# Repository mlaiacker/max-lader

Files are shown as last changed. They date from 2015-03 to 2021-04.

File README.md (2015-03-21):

# max-lader
DIY Battery Charger, 12V Input, 0-25V Output, 5.5A, using AVR
With these components the charger is limited to about 120W and maximum input voltage of about 15V

See also: 
http://mlaiacker.no-ip.org/Modellbau/AVR-Lader/
## Charging
Type | Cells
----|----
LiPo | 1-6
LiFe | 1-7
NiMh/NiCa| 1-16
PB | 1-6 (2-12V)
Programmable Power Supply | 0-25V 0-5.5A
## Characteristics
Parameter | Value
----|----
Input Voltage | 11-15V
Output Voltage | 0-25V
Voltage Resolution | 0-13V 14mV , >13V 27mV 
Output Current | 0-5.5A
Current Resolution | 6.6mA
Power | up to 125W
PWM Switching Frequency | 31.25kHz (16MHz/512)
PWM Resolution | 9 Bits
Efficiency | up to 89%
## Images
MAX-Lader with big heat sink which not really necessary.<br>
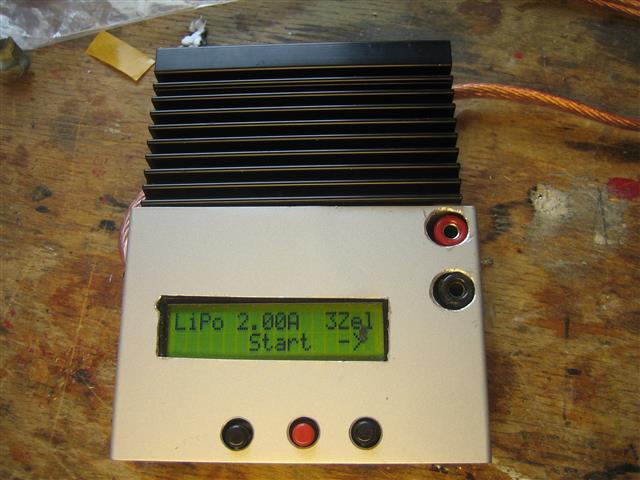
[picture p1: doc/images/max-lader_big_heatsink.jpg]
max-lader

<br>
The charger without the LCD and enclosure<br>
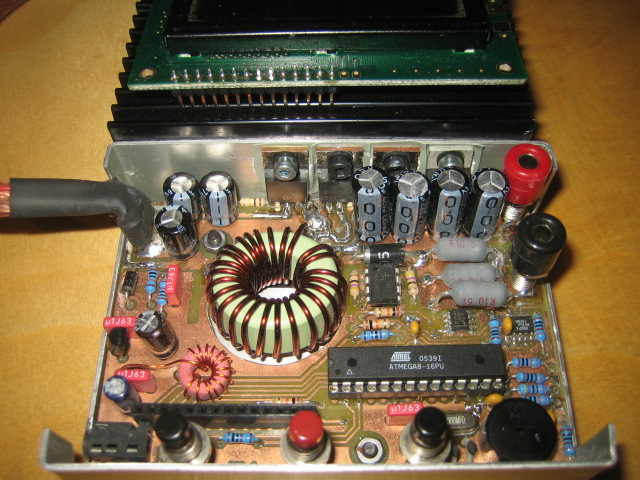
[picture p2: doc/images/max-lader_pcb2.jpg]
max-laderpcb

## Electronics
The electronics are mostly thru hole and optimized for home production double sided PCB. The output voltage and current is regulated using a buck/boost converter which is software controlled by the AVR. The main coil is self made which is easy. The electronics fit nicely into the enclosure but the space is limited that is why there is no balancer electronics included. The LCD should be 2x16 (HD44780) characters with 14 or 16 pins on the lower left corner. The MOSFETs and diode have to be mounted electrical isolated from the enclosure/heat sink. Mounting the Mosfets behind the output caps is a bit tricky. The output caps have to be LowESR types. The resistors for the voltage dividers for the output and current should be 0.1% types to ensure the correct voltages when charging LIPOs. The input is reverse voltage protected but the output is not. Output caps will blow when a battery is connected the wrong way.

Using bigger or more MOSFETs and bigger coil and smaller shunt resistors should enable more output power. The maximum input voltage is limited by the ICL7667 max. voltage and max. GS-Voltage of the P-Channel Mosfet (IRF4905)
## Software
The Software is heavily optimized for size to fit in the ATmega8 that was originally used. It can be build for the ATmega8 or for the newer ATmega168. Using the ATmega168 will enable some more functions like display of data from a Robbe Top Lipo Equalizer 6S when connected to the serial port. The menu is in German but very easy: <br>
Step 1: Select battery type<br>
Step 2: Set Cell count<br>
Step 3: Set Current<br>
Step 4: Connect battery (charging will start automatically when a battery is connected) <br>
## Bootloader
There is no ISP connector on the PCB so you have to program the bootloader before installing the AVR to the charger. The bootloader is activated when the middle button is pressed during power up. The program can be loaded using the serial interface using stk500v1 protocol with avrdude.

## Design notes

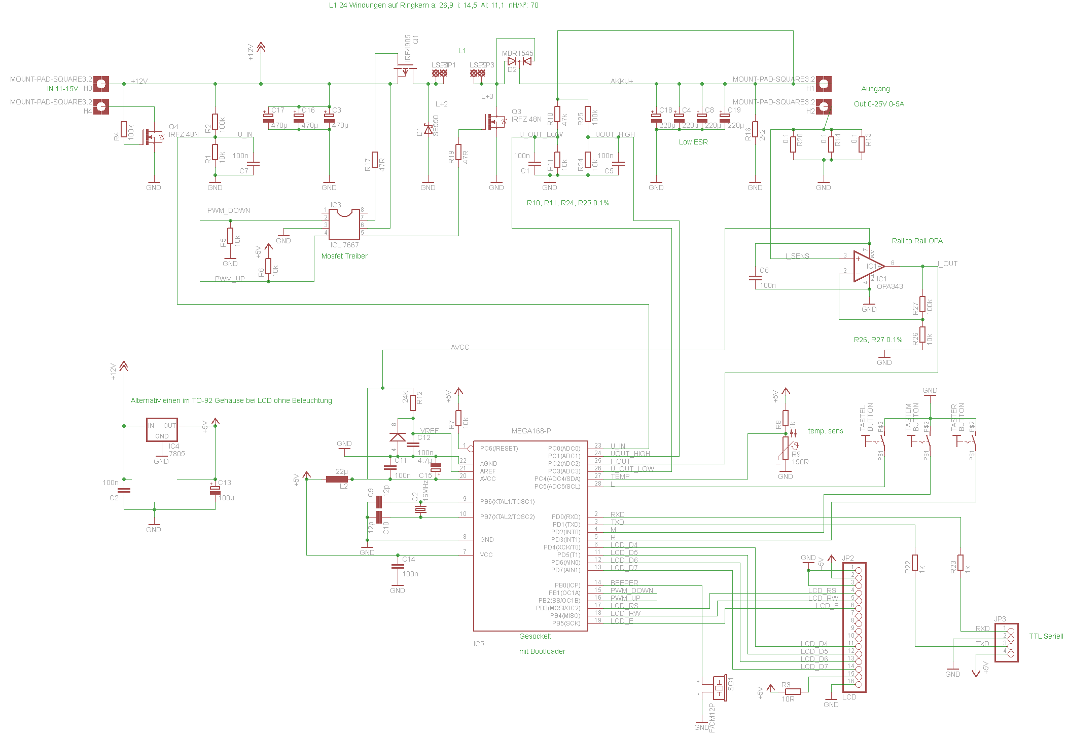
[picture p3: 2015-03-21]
hardware/eagle/max-lader-1.3.png

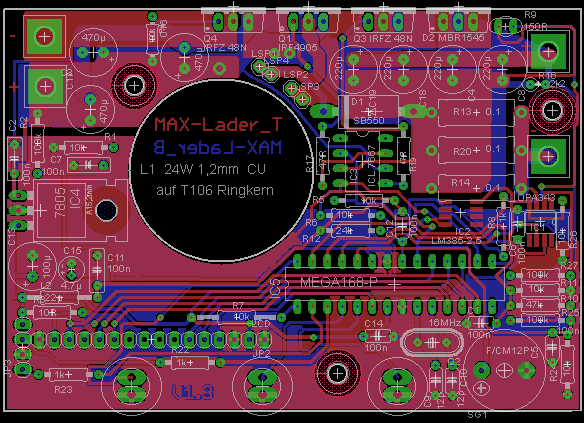
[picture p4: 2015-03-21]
hardware/eagle/max-lader-1.3_pcb.png

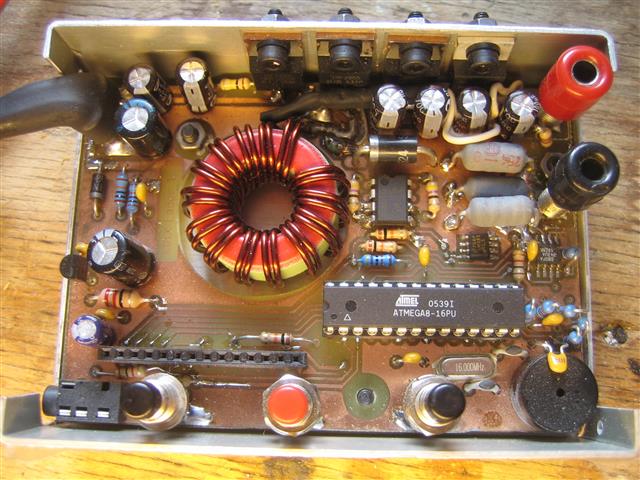
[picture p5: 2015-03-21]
doc/images/max-lader_pcb.jpg

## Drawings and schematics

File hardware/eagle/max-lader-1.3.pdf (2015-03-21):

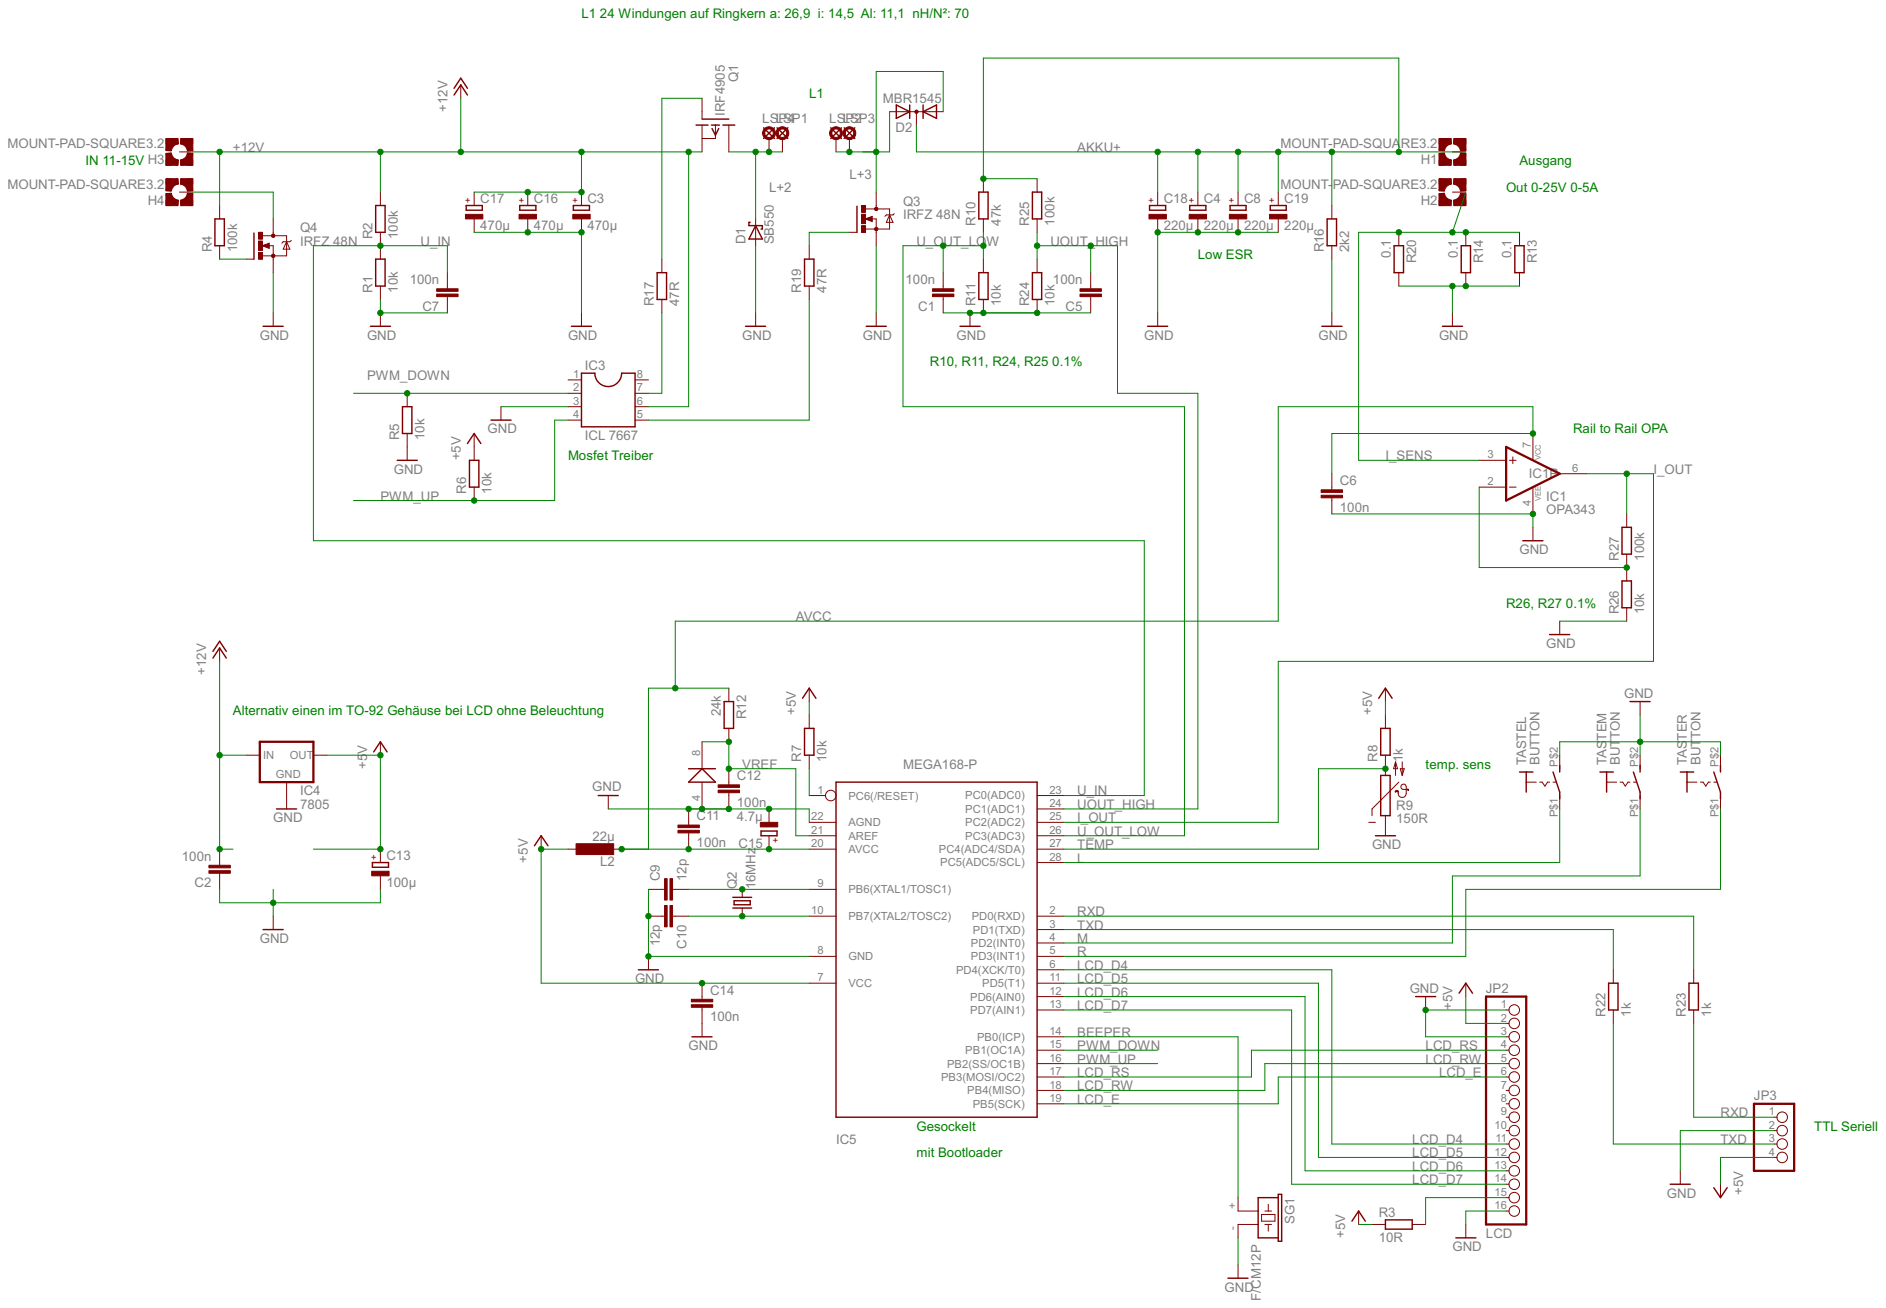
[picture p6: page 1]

L1 24 Windungen auf Ringkern a: 26,9 i: 14,5 Al: 11,1 nH/N²: 70

Rail to Rail OPA

Alternativ einen im TO-92 Gehäuse bei LCD ohne Beleuchtung

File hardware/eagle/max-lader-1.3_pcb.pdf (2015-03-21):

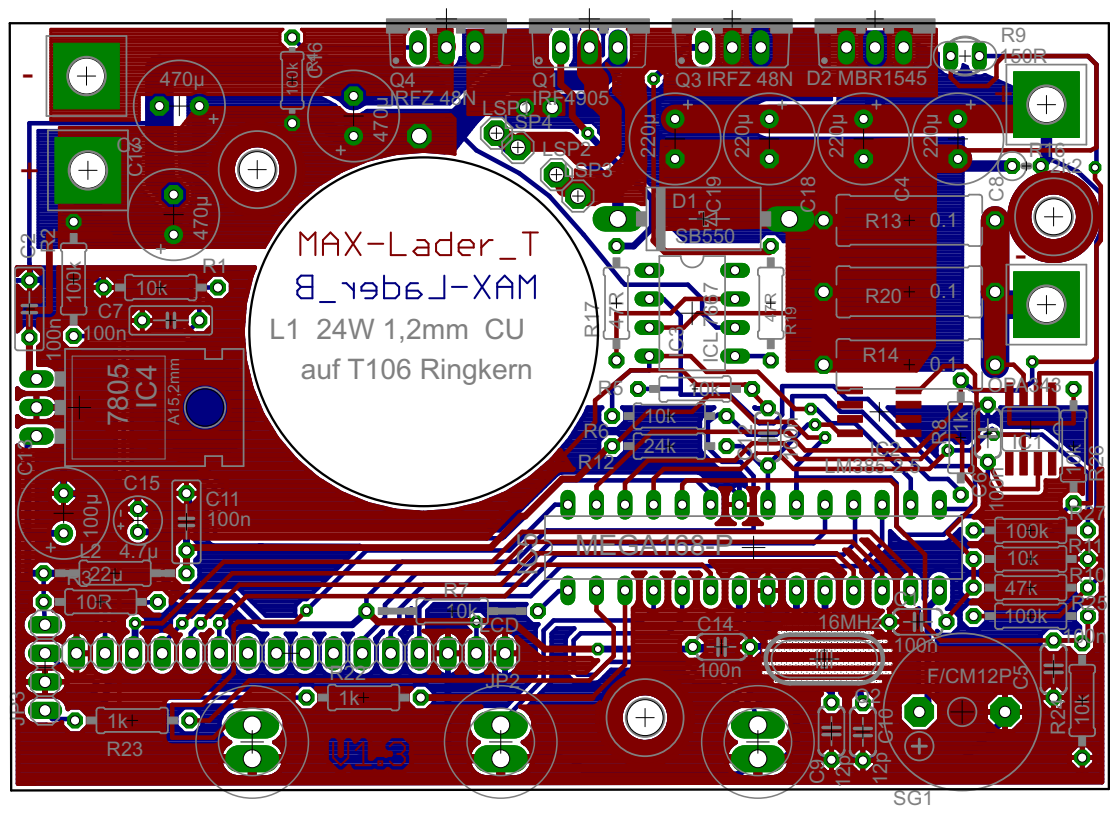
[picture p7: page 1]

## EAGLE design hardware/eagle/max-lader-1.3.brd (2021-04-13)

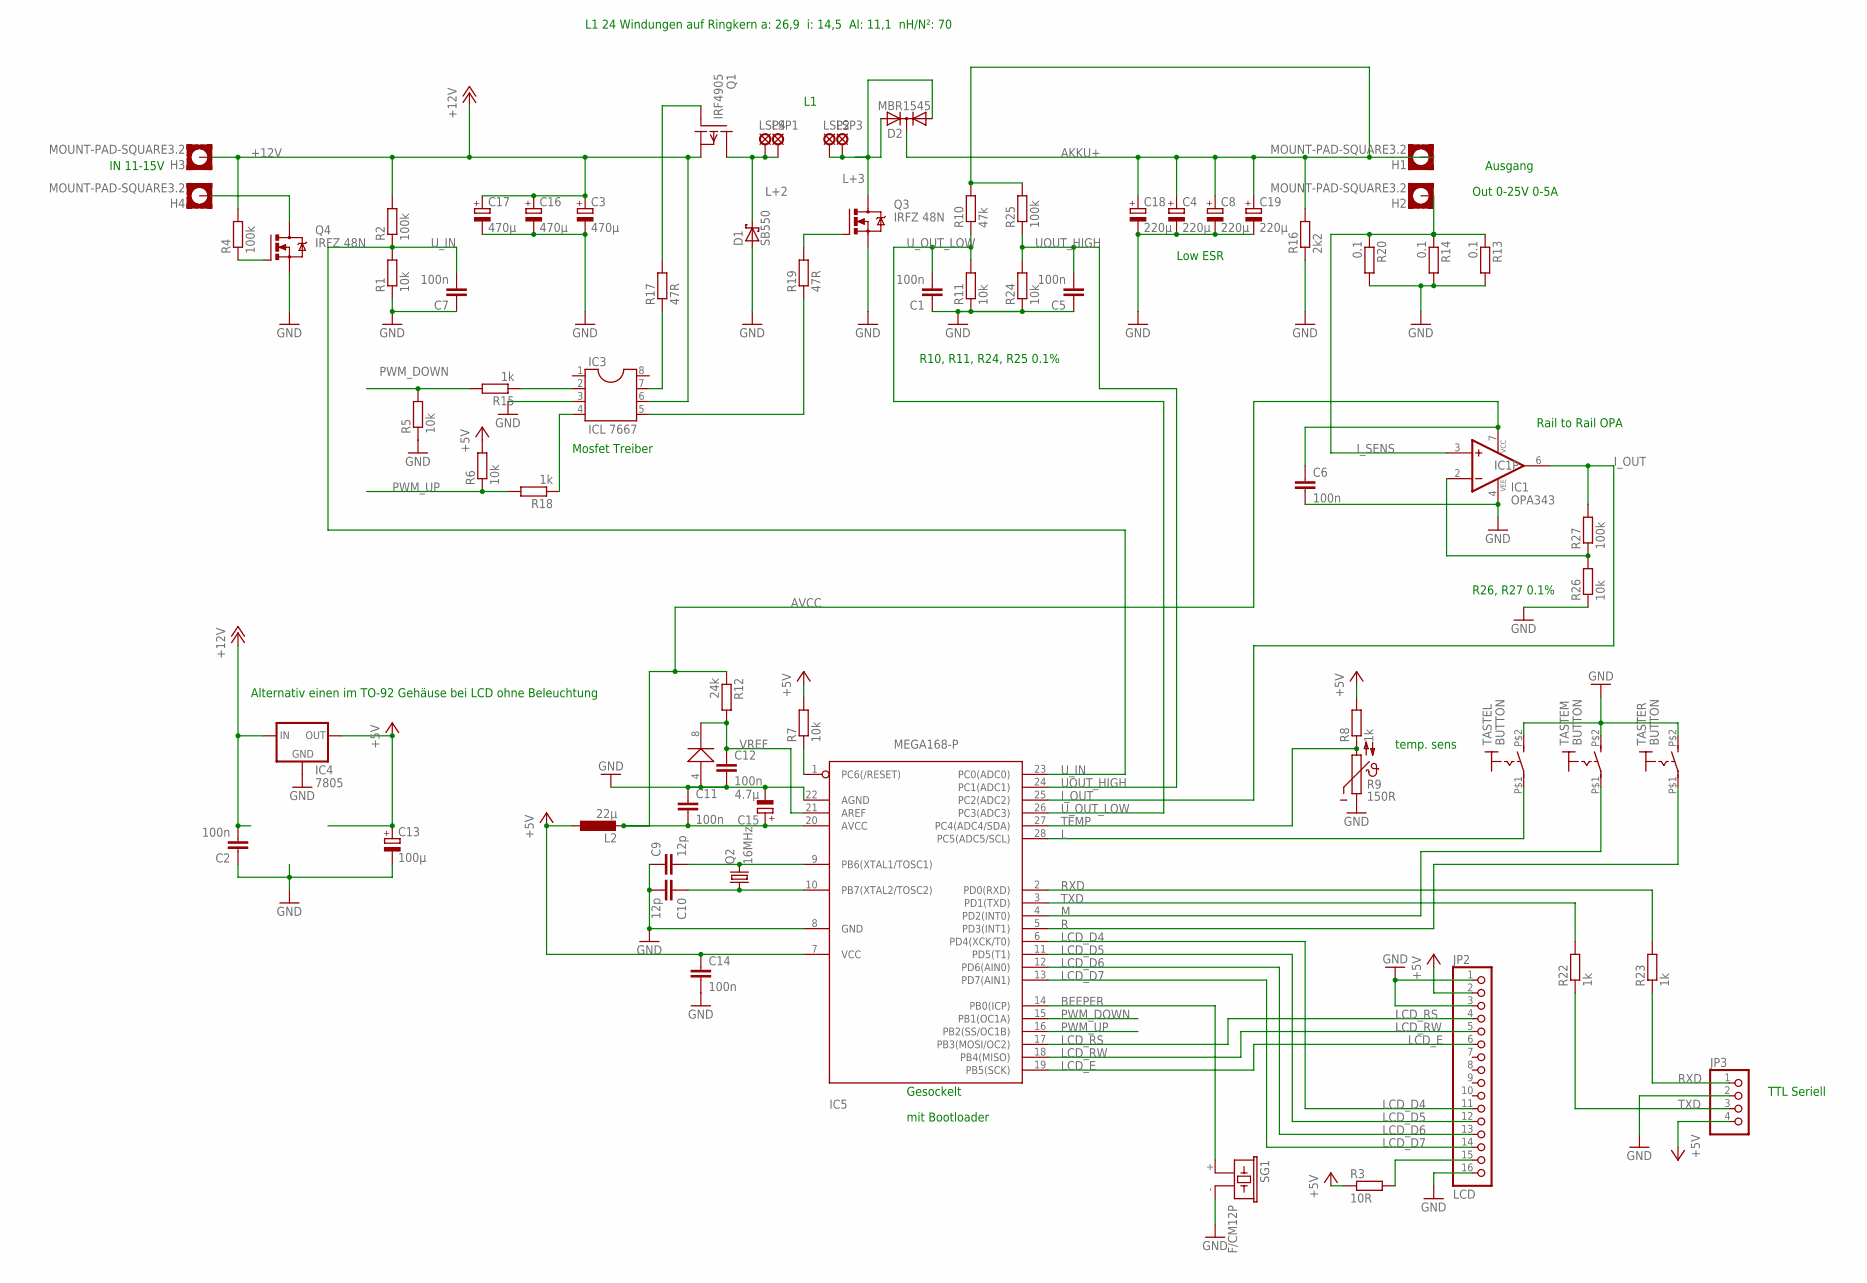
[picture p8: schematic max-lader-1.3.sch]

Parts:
C1, C5, C6, C12, C14: 100n; C050-024X044
C2, C7, C11: 100n; C050-025X075
C3, C16, C17: 470µ; E3,5-8
C4, C8, C18, C19: 220µ; E3,5-8
C9, C10: 12p; C050-024X044
C13: 100µ; E3,5-8
C15: 4.7µ; E2-4
D1: SB550; DO201T15
D2: MBR1545; TO220ABS
H1, H2, H3, H4: MOUNT-PAD-SQUARE3.2; 3,2-PAD-SQUARE
IC1: OPA343; SO08
IC2: LM385-2.5; SO08
IC3: ICL 7667; DIL08
IC4: 7805; 78XXL
IC5: MEGA168-P; DIL28-3
JP2: LCD; 1X16
JP3: PINHD-1X4; 1X04
L2: 22µ; 0207/12
LSP1, LSP2, LSP3, LSP4: SE13
Q1: IRF4905; TO220V
Q2: 16MHz; HC49/S
Q3, Q4: IRFZ 48N; TO220BV
R1, R11, R24, R26: 10k; 0207/10
R2, R25, R27: 100k; 0207/10
R3: 10R; 0207/10
R4: 100k; 0204/7
R5, R6, R7: 10k; R0805
R8, R15, R18, R22, R23: 1k; R0805
R9: 150R; P642
R10: 47k; 0207/10
R12: 24k; 0207/10
R13, R14, R20: 0.1; P0613/15
R16: 2k2; 0207/2V
R17, R19: 47R; 0207/10
SG1: F/CM12P
TASTEL: BUTTON; BUT
TASTEM: BUTTON; BUT
TASTER: BUTTON; BUT

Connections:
+5V: C13.+, C14.1, IC4.OUT, IC5.7 (VCC), JP2.2, JP3.4, L2.1, R3.1, R6.2, R7.2, R8.2
+12V: C2.2, C3.+, C16.+, C17.+, H3.B3,2, IC3.6, IC4.IN, Q1.3 (S), R2.2, R4.2
AKKU+: C4.+, C8.+, C18.+, C19.+, D2.C, H1.B3,2, R10.2, R16.2, R25.2
AVCC: C6.1, C11.2, C15.+, IC1.7 (VCC), IC5.20 (AVCC), L2.2, R12.1
BAT-: H4.B3,2, Q4.D
BEEPER: IC5.14 (PB0(ICP)), SG1.+ (1)
BOOST_CTRL: IC3.5, R19.1
BOOST_GATE: Q3.G, R19.2
BUCK_CTRL: IC3.7, R17.1
BUCK_GATE: Q1.1 (G), R17.2
GND: C1.1, C2.1, C3.-, C4.-, C5.1, C6.2, C7.1, C8.-, C9.1, C10.2, C11.1, C12.2, C13.-, C14.2, C15.-, C16.-, C17.-, C18.-, C19.-, D1.A, IC1.4 (VEE), IC2.4 (ANODE), IC3.3, IC4.GND, IC5.8 (GND), IC5.22 (AGND), JP2.1, JP2.3, JP2.16, JP3.2, Q3.S, Q4.S, R1.1, R5.1, R9.1, R11.1, R13.2, R14.2, R16.1, R20.2, R24.1, R26.1, SG1.- (2), TASTEL.P$2 (S), TASTEM.P$2 (S), TASTER.P$2 (S)
INPUT_GATE: Q4.G, R4.1
I_OUT: IC1.6 (OUT), IC5.25 (PC2(ADC2)), R27.2
I_SENS: H2.B3,2, IC1.3 (+IN), R13.1, R14.1, R20.1
L: IC5.28 (PC5(ADC5/SCL)), TASTEL.P$1
L+2: D1.C, LSP1.MP, LSP4.MP, Q1.2 (D)
L+3: D2.A1, D2.A2, LSP2.MP, LSP3.MP, Q3.D
LCD_D4: IC5.6 (PD4(XCK/T0)), JP2.11
LCD_D5: IC5.11 (PD5(T1)), JP2.12
LCD_D6: IC5.12 (PD6(AIN0)), JP2.13
LCD_D7: IC5.13 (PD7(AIN1)), JP2.14
LCD_E: IC5.19 (PB5(SCK)), JP2.6
LCD_RS: IC5.17 (PB3(MOSI/OC2)), JP2.4
LCD_RW: IC5.18 (PB4(MISO)), JP2.5
M: IC5.4 (PD2(INT0)), TASTEM.P$1
unnamed: IC3.4, R18.1
unnamed: IC5.1 (PC6(/RESET)), R7.1
unnamed: IC3.2, R15.1
unnamed: C9.2, IC5.9 (PB6(XTAL1/TOSC1)), Q2.2
unnamed: C10.1, IC5.10 (PB7(XTAL2/TOSC2)), Q2.1
unnamed: JP2.15, R3.2
unnamed: IC1.2 (-IN), R26.2, R27.1
PWM_DOWN: IC5.15 (PB1(OC1A)), R5.2, R15.2
PWM_UP: IC5.16 (PB2(SS/OC1B)), R6.1, R18.2
R: IC5.5 (PD3(INT1)), TASTER.P$1
RXD: IC5.2 (PD0(RXD)), R23.2
RXD_OUT: JP3.1, R23.1
TEMP: IC5.27 (PC4(ADC4/SDA)), R8.1, R9.2
TXD: IC5.3 (PD1(TXD)), R22.2
TXD_OUT: JP3.3, R22.1
UOUT_HIGH: C5.2, IC5.24 (PC1(ADC1)), R24.2, R25.1
U_IN: C7.2, IC5.23 (PC0(ADC0)), R1.2, R2.1
U_OUT_LOW: C1.2, IC5.26 (PC3(ADC3)), R10.1, R11.2
VREF: C12.1, IC2.8 (CATODE), IC5.21 (AREF), R12.2

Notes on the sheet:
Ausgang
temp. sens
Rail to Rail OPA
Gesockelt
mit Bootloader
TTL Seriell
Mosfet Treiber
IN 11-15V
Out 0-25V 0-5A
R10, R11, R24, R25 0.1%
R26, R27 0.1%
Low ESR
L1 24 Windungen auf Ringkern a: 26,9 i: 14,5 Al: 11,1 nH/N²: 70
Alternativ einen im TO-92 Gehäuse bei LCD ohne Beleuchtung

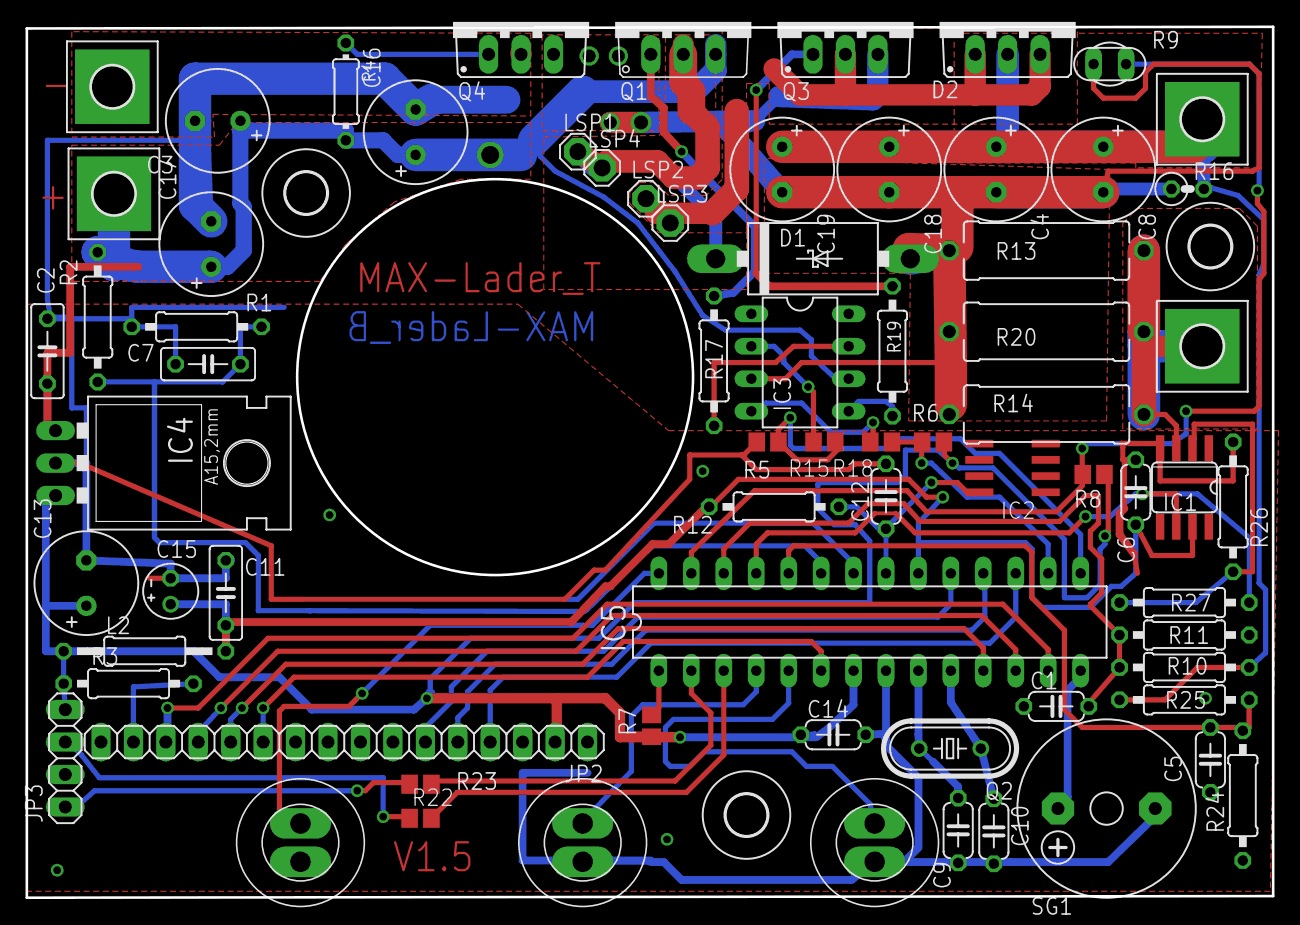
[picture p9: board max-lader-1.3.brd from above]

Board: 2 copper layers, 97.6 x 68.2 mm, 74 parts (0 on the bottom side), 44 nets.

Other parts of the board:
U$2, U$3, U$4: 3,2

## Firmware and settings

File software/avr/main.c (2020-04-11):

/*	 main.c
* max-Lader 
* entwickelt von:
* Maximilian Laiacker post@mlaiacker.de http://mlaiacker.de/
*
*/
#include <avr/interrupt.h>
#include <avr/io.h>
#include <avr/wdt.h> 
#include <avr/eeprom.h>

#include "global.h"
#include "usart.h"
#include "a2d.h"
#include "lcd.h"
#include "pwm.h"
#include "rtc.h"
#include "pwmregler.h"
#include "laden.h"
#include "ladermenu.h"

#include "migration8-168.h"

struct
{
	t_Time tSekunde,tDisplay;
} maindata;

void uartOutput(void);

//-------------Initalisierung------------------
// da die init fuktionen sowiso nur ein mal im programm aufgerufen werden stehen sie hier "inline"
// ist zwar nicht so übersichtlich spart aber mindestens 4 byte pro init funktion
void init(void){
	#ifdef BEEP_ON
	BEEP_INIT;
	#endif
	
#ifdef UART
#ifdef DEBUG_OSC
	oscData.trigger_ch=254;
	oscData.index = 0;
#endif
// Serielle Schnittstelle intalisieren
	#if defined (__AVR_ATmega168__)
		wdt_disable();
		UBRRL = (uint8_t)(F_CPU/(UART_BAUD_RATE*8L)-1);
		UBRRH = (F_CPU/(UART_BAUD_RATE*8L)-1) >> 8;
		UCSR0A = _BV(U2X0);
		UCSR0B = _BV(TXEN)|_BV(RXEN)|_BV(RXCIE);
//		UCSRB = 0x98;        // 1001 1000
                       // Receiver enabled, Transmitter enabled
                       // RX Complete interrupt enabled
	#elif defined (__AVR_ATmega8__)
		UBRRL = (uint8_t)(F_CPU/(UART_BAUD_RATE*8L)-1);
		UBRRH = (F_CPU/(UART_BAUD_RATE*8L)-1) >> 8;
		UCSRA = _BV(U2X);
//		UBRRL = UART_UBRRL; // Bautrate setzten
		UCSRB = _BV(TXEN); // senden aktivieren, das Programm macht nur Ausgaben über die serielle Schnittstelle
	#endif

	#endif
	lcdInit();


// timer0 für Zeitmessung
	Time=0;
	// Counter Register
	TCNT0=RTC_START_VAL;
	// Overflow enable
	#ifdef TIMSK
	TIMSK |= _BV(TOIE0);
	#else
	TIMSK0 |= _BV(TOIE0);
	#endif
	#ifdef TCCR0
	// prescaler select F_CPU/256
	// ergibt einen overflow alle 16MHz/256/250 = 4 ms
	TCCR0 = 0x04;
	#else
	TCCR0B = 0x04;
	#endif
	
	
	ADMUX = (0<<ADLAR) | (ADC_REFERENCE<<6);
	ADCSR = ((0<<ADFR)|(1<<ADEN)|(1<<ADIE)|(1<<ADSC)|(1<<ADIF) | ADC_PRESCALE);

#ifdef PWM1
#ifdef PWM_DOWN_9BIT
  TCCR1A = (1<<COM1A1|0<<COM1A0|1<<COM1B1|1<<COM1B0|1<<WGM11|0<<WGM10); 
#else
  TCCR1A = (1<<COM1A1|0<<COM1A0|1<<COM1B1|1<<COM1B0|0<<WGM11|1<<WGM10); 
#endif
  TCCR1B = (0<<WGM13|1<<WGM12|1<<CS10|0<<CS11|0<<CS12);
#endif
#ifdef PWM12
#endif
    cbi(PWM_UP_PORT,PWM_UP_BIT); // port = 0
    sbi(PWM_UP_DDR,PWM_UP_BIT); // OC1B
  
	sei(); // interupt enable

	TASTE_L_INIT;
	TASTE_M_INIT;
	TASTE_R_INIT;
	ladenOff();
	BEEP_ON;
	lcdGotoY(0);
	#if defined (__AVR_ATmega168__)
		lcdPrint("   MAX-Lader16  ");
	#elif defined (__AVR_ATmega8__)
		lcdPrint("   MAX-Lader    ");
	#else
#error "not supported MCU"
	#endif
	lcdGotoY(1);
	lcdPrint("Version:");
	lcdNum(LADER_VERSION,2,1);
	rtcDelay(900);
	BEEP_OFF;
	rtcDelay(900);

// zu letzt gewählten lade modus aus dem eeprom lesen
	charger.mode = eeprom_read_byte(&eeChargeMode);
	if(charger.mode>(MODE_NUM-1)) charger.mode = 0; // auf plausibilität prüfen
	readSettings(charger.mode); // die Einstellungen zum aktuellen Modus aus eeprom lesen
}// init end

/*---------------- Functions -------------------------*/


#ifdef UART

#if defined (__AVR_ATmega168__)
#include <stdlib.h>
#include <string.h>
int balancer_parse(unsigned char c, t_balancer_state *state)
{
  switch(state->state)
  {
    // sync
    case 0:if(c==0x0a){ state->state++; state->index=0; state->cell=0;} break;
    case 1:if(c==0xf5) state->state++; else state->state=0; break;
    case 2:if(c==0x0c) state->state++; else state->state=0; break;
    // unkown byte
    case 3:if(c!=0) { state->state++; state->data.byte4=c; } else state->state=0; break;
    // cell count char
    case 4:if(c!=0)
           { 
             state->state++; 
             state->data.cells = c-'0'; 
             if((state->data.cells == 0) || (state->data.cells > MAX_BALANCER_CELL)) state->state=0;
           }
           else state->state=0; 
           break;
    // reading of cell data
    case 5:if(c!=0)
           {
             state->cell_string[state->index]=c;
             state->cell_string[state->index+1]=0;
             state->index++;
             // the cell voltage is 4 bytes long 
             if(state->index>=4)
             {
               state->data.mv[state->cell] = strtol(state->cell_string, NULL, 16);
               state->cell++; 
               state->index=0;
               if(state->cell>=state->data.cells)
               {
                 state->state++;
               }
             }
           }
           else state->state=0; 
           break;
     // last 4 bytes
     case 6:if(c!=0)
           {
             state->cell_string[state->index]=c;
             state->cell_string[state->index+1]=0;
             state->index++;
             //  4 bytes long 
             if(state->index>=4) 
             {
               state->data.last_data = strtol(state->cell_string, NULL, 16);
               state->index=0;
               state->state++;
             }
           }
           else state->state=0; 
           break;
     case 7:state->state=0;
           if(c==0x0d) return -1;
           break;
     default: state->state=0; break;
  }
  return 0;
}
#endif
#ifdef DEBUG_OSC
u16 uart_data_send=0;
u16 uart_busy=0;
void uartOsc(void)
{
	if(oscData.trigger_ch==255 && uart_data_send==0 && uart_busy==0)
	{
		usartPutc(0xff);
		usartPutc(0xaf);
		usartPutc(0xbf);
		uart_busy=1;
	}
	if(uart_busy && uart_data_send<sizeof(oscData))
	{
		usartPutc(((u08*)&oscData)[uart_data_send]);
		uart_data_send++;
	}
	if(uart_data_send==sizeof(oscData) && uart_busy==1)
	{
		uart_busy = 0;
		oscData.trigger_ch=254;
		uart_data_send = 0;
	}
}
#endif

void uartOutput(void)
{
#ifdef DEBUG_OSC
	if(uart_busy) return;
#endif
	usartNum(charger.sekunden,5,0); // Ladezeit
	usartNum(charger.u,4,2); // Ausgangsspanung aktuell
	usartNum(charger.i,4,3); // Ausgangsstrom
	usartNum(charger.c,4,2); // geladene Kapazität
	usartNum(charger.dut,0,0); // Spanungsänderung in mv/Minute
	usartNum(charger.ddutt,0,0); // Änderung der Spannungsänderung in mv/Minute²
	usartNum(regler.pwm/PWM_DIV,0,0); // pwm zustand
	usartNum(regler.uIn,4,2); // Eingangsspannung
	usartNum(regler.temp,0,0); // "Temperatur" der Endstufe
	usartNum(charger.uOut,4,2); // Ausgangsspanung stromlos
	usartPutc('\r');
	usartPutc('\n');
}

#endif
/*----------------------------------------------------*/

/*----------------Timer Interrupts--------------------*/
ISR(TIMER0_OVF_vect)
{
  TCNT0=RTC_START_VAL;
  Time+=RTC_OVERFLOW_TIME;
#ifdef RTC_OVERFLOW_FRACTION
  Time_us+=RTC_OVERFLOW_FRACTION;
  if(Time_us>=1000)
  {
	Time+=1;
	Time_us-=1000;
  }
#endif
}
/*----------------------------------------------------*/

/*----------------Main Loop---------------------------*/
int main(void)
{
#if defined (__AVR_ATmega168__)
    MCUSR = 0;
	t_balancer_state	bstate;
	u08 stk500v1_parse = 0;
	wdt_reset();
	wdt_disable();
#endif
	init();
	// watchdog einschalten
	wdt_enable(WDTO_1S);
	
	for(;;)
	{
		wdt_reset();
#if defined (__AVR_ATmega168__)
#ifdef DEBUG_OSC
		uartOsc();
#endif
		if(usart_unread_data()!=0)
		{
			u08 c = usart_getc();
			if(balancer_parse(c,&bstate))
			{
				memcpy(&bdata, &(bstate.data), sizeof(bdata));
				if(bdata.cells!=0)
				{
					cell_avg = 0;
					for(u08 i=0;i<bdata.cells;i++)
					{
						cell_avg += bdata.mv[i];
					}
					cell_avg /= bdata.cells;
				}
			}
			if(regler.status!=REGLER_STATUS_ON)
			{
				if(stk500v1_parse==0){
					if((c=='1') || (c=='u') || (c=='0')) stk500v1_parse++;
				} else
				if(stk500v1_parse==1){
					if(c==' '){
						rtcDelay(1500); // wait for WDT to reset MCU
					}
					stk500v1_parse = 0;
				}
			}
		}
#endif
		if(maindata.tDisplay <= Time)
		{
			laden();
			showMenu();
			maindata.tDisplay += MENU_DISPLAY_INT;
		}
		if(maindata.tSekunde <= Time) // jede sekunde
		{
			maindata.tSekunde += 1000L;
			menu.blinken = !menu.blinken;
			#ifdef UART
			if(regler.status==REGLER_STATUS_ON)	uartOutput();
			#endif
			ladenSekunde();
			pwmreglerSekunde();
		}

	}// for(ever) 
}// main

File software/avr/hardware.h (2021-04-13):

#ifndef HARDWARE_H
#define HARDWARE_H

#if defined (__AVR_ATmega168__)
#include "migration8-168.h"
#endif

#define LADER_VERSION	(19)

#ifndef F_CPU
	#if defined (__AVR_ATmega168__)
		#define F_CPU        16000000L              		// 16MHz processor
	#elif defined (__AVR_ATmega8__)
		#define F_CPU        16000000L               		// 16MHz processor
	#endif
#endif

/* ### ADC ### */

#define UOUT_LOW	3
#define UOUT		1
#define UIN			0
#define IOUT		2
//#define TASTEN	3
#define TEMP		4


// Refferenzspannung 2.500V
#define U_REF	250 // in mv/10

// Strommessungs Shunt
//#define R_SENS		(0.1/3)	//Ohm

// Verstärkung der Strommessung = 11
// 1 bit = 2500mV*3/(4096*11*0.1Ohm) = 9375/5632 ca.: 5/3 mA
// der maximal messbare Strom liegt damit bei 6,826 A



// für SHUNT=0.1ohm/3 Imax=5.5A
//#define IOUT2BITS(x) ((x)*3/5)
#define IOUT2BITS(x) ((x)*(4096L*11L)/(2500L*30L))
//#define BITS2IOUT(x) ((x)*5/3)
#define BITS2IOUT(x) ((x)*2500L*30L/(4096L*11L))
#define IOUT_GRENZWERT	IOUT2BITS(6200L)
// pro bit ausgangsstrom sinkt die Klemmenspannung (in bits) um diesen Wert bei 0.1/3 Ohm shunt
#define U_SENS(I)	((I)/121) //BITS2IOUT(I)*R_SENS*UOUT2BITS(x) = 9375/5632 * 0.1/3 * 2048/1375 = 1/121
#define IOUT_MAX		(6000) // mA

/*
// für doppelten strom
// für SHUNT=0.1ohm/6 Imax=9.95A
#define IOUT2BITS(x) ((x)*(4096L*11L)/(2500L*60L))
#define BITS2IOUT(x) ((x)*2500L*60L/(4096L*11L))
#define IOUT_GRENZWERT	IOUT2BITS(11000L)
// pro bit ausgangsstrom sinkt die Klemmenspannung (in bits) um diesen Wert
#define U_SENS(I)		((I)/60L)
#define IOUT_MAX		(9950L) // mA
*/


//spannungsteiler 10/110
#define UOUT2BITS(x) ((short)(((long)(x)<<11L)/1375L))	

#define BITS2UOUT(x) ((short)(((long)(x)*1375L)>>11L))	//10*mV (250*110)/(10*4096) = 2750/5096 = 1375/2048

// spannungsteiler für eingangsspannung
// gleicher teiler wie am ausgang (1/11)
#if defined (__AVR_ATmega168__)
	#define UIN2BITS(x) UOUT2BITS(x)
	#define BITS2UIN(x) BITS2UOUT(x)
#elif defined (__AVR_ATmega8__)
//250*11/1024...
	#define UIN2BITS(x) (((x)*3)>>1)
	#define BITS2UIN(x) (((x)<<3)/12) //10*mV (Teiler=1/11 )
#endif


// spannungsteiler 10/57
#define BITS2UOUTL(x) ((short)(((long)(x)*1425L)>>12L))	//10*mV (250*57)/(10*4096) = 1425/4096

#define UOUT_LOW_AKTIV	(1300)	//unterhalb dieser spannung uout_low benutzen

// umrechnung von adc werten (10bit) in temeratur in °C
#define BITS2TEMP(x) ((x)*(x)/1864L + (x)*100/-282 + 83L) // aus messwerten ermittelt und dann mit matlab(basic fitting) ausgerechnet

#define ADC_PRESCALE			ADC_PRESCALE_DIV64
#define ADC_REFERENCE			ADC_REFERENCE_AREF

#define A2D_SCAN_CHANNELS	(5)
#define A2D_SCAN_BUF	(16)

// oversampling benutzen statt laufende mittelwert bildung
//#define OVERSAMPLING
#define OVERSAMPLING_RATE		8
/* Laden*/

#define P_MAX			(10000) //10*mW  maximale Ausgangsleisung

/* ### Beep ### */
#define BEEP_DDR		DDRB
#define BEEP_PORT		PORTB
#define BEEP_BIT		0
#define BEEP_ON			sbi(BEEP_PORT,BEEP_BIT)
#define BEEP_OFF		cbi(BEEP_PORT,BEEP_BIT)
#define BEEP_INIT		(BEEP_DDR |= (1<<BEEP_BIT))

#define BEEP_LADEN_COUNT 5 // wie offt peipt's wenn die ladung beendet wurde
#define BEEP_ERROR_COUNT 120

/* ### LCD ### */
#define LCD_PORT_INTERFACE
#define LCD_CTRL_PORT	PORTB
#define LCD_CTRL_DDR	DDRB
#define LCD_CTRL_RS		3
#define LCD_CTRL_RW		4
#define LCD_CTRL_E		5
#define LCD_CTRL_E_PORT	PORTB
#define LCD_CTRL_E_DDR	DDRB
// port you will use for data lines
#define LCD_DATA_POUT	PORTD
#define LCD_DATA_PIN	PIND
#define LCD_DATA_DDR	DDRD
// access mode you will use (default is 8bit unless 4bit is selected)
#define LCD_DATA_4BIT

#define LCD_LINES				2	// visible lines
#define LCD_LINE_LENGTH			16	// line length (in characters)

//#define LCD_DELAY	asm volatile ("nop\n nop\n nop\n nop\n nop\n nop\n nop\n nop\n");
#define LCD_DELAY	asm volatile ("nop\n nop\n nop\n nop\n nop\n nop\n nop\n");

/* ### Tasten ### */
//#define TASTEN_ADC
// Tasten sind am ADC3
#define TASTE_L	(bit_is_clear(TASTE_L_PIN,TASTE_L_BIT))
#define TASTE_M	(bit_is_clear(TASTE_M_PIN,TASTE_M_BIT))
#define TASTE_R	(bit_is_clear(TASTE_R_PIN,TASTE_R_BIT))

// tasten sind an einzelnen eingängen
#define TASTE_L_PORT	PORTC
#define TASTE_L_PIN		PINC
#define TASTE_L_BIT		5
// pullup einschalten
#define TASTE_L_INIT (TASTE_L_PORT|=(1<<TASTE_L_BIT))

#define TASTE_M_PORT	PORTD
#define TASTE_M_PIN		PIND
#define TASTE_M_BIT		2
#define TASTE_M_INIT (TASTE_M_PORT|=(1<<TASTE_M_BIT))

#define TASTE_R_PORT	PORTD
#define TASTE_R_PIN		PIND
#define TASTE_R_BIT		3
#define TASTE_R_INIT (TASTE_R_PORT|=(1<<TASTE_R_BIT))


/* ### PWM ### */
#define PWM1 // PWM1A und PWM1B sind für UP und DOWN

//#define PWM12 // timer2 ist für PWM_UP //timer 1 ist für down

#define PWM_UP_PORT		PORTB
#define PWM_UP_DDR		DDRB
#define PWM_UP_BIT		2
//#define PWM_UP_9BIT

#define PWM_DOWN_PORT	PORTB
#define PWM_DOWN_DDR	DDRB
#define PWM_DOWN_BIT	1
//#define PWM_DOWN_9BIT
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

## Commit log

2015-03-21 added schematics for hw version 1.3
    [max-lader-1.3.brd, max-lader-1.3.sch]
2019-11-13 added progam_all target to flash bootloader and main programm at once and fixed size print
2019-11-13 fixed size print in Makefile
2019-11-13 added LiHv (4,3V cell) support, show end voltage when setting up cell count, show input voltage on start menu, moved to version 1.6
2019-11-13 eagle files
    [max-lader-1.3.brd, max-lader-1.3.sch]
2019-11-15 changed pwm control algorithm to PID works better, added "oscilloscope" function for debug of PWM with matlab plotting script
2020-03-17 added hyteresis to pwm control, tested on atmega168, fixed debug trigger bug
    [hardware.h, pwmregler.c]
2020-04-10 changed charger logic a bit and code style cleanup
2020-04-10 removed pwm control debug feature for now
2021-04-13 layout version 1.5 with 1k protection resistors for icl7667 failure on overvoltage, it will kill the atmega168 without
    [max-lader-1.3.brd, max-lader-1.3.sch]
